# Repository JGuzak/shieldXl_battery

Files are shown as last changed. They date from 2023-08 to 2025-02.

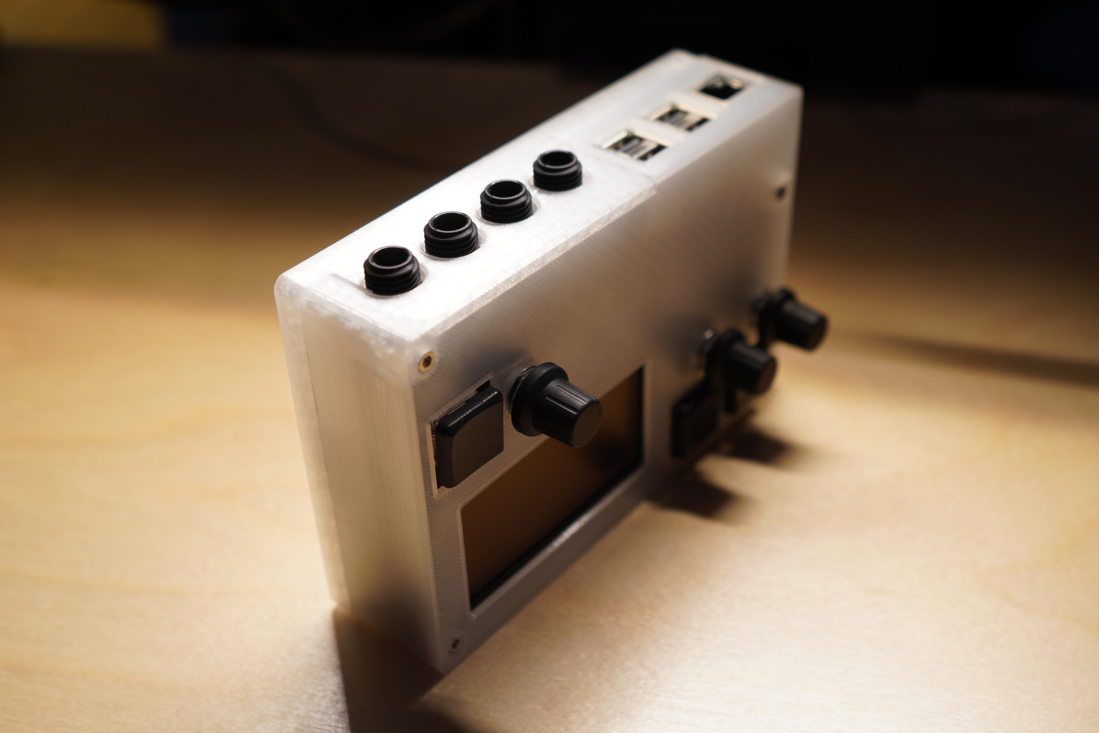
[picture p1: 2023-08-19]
images/assembled_2.JPG

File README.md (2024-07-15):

# ShieldXl Battery Case

A case and internal battery mod for the [shieldXl](https://github.com/okyeron/shieldXL/)



## DISCLAIMERS

This mod is not supported by Denki Oto and they are not responsible for assisting with assembly or troubleshooting.

The USB and Ethernet ports are aligned for raspberry pi 3B+. Raspberry pi 4 will work but the cutouts will not be aligned correctly.

## Kits for the Pi 3B+ flavor of this case are available of on the [Modbang shop](https://www.modbang.com/modbang-shop/shieldxlbatterykit).

| Table of Contents |
| - |
| Credits |
| Use |
| BOM |
| Case |
| Installation |
| Troubleshooting |



## Credits

Referenced model was designed by CarlosUnch, John Park and Steven Noreyko.

Project inspiration from Peter Kassel
FAQ/troubleshooting contributions:
- Moneo
- Teamac

## Use

Toggle the power switch to turn on the battery (Blue light will illuminate and green light should flash)

## BOM



- 1x assembled shieldxl `*` ([bom](https://github.com/okyeron/shieldXL/tree/main/bom) for the shieldXl is available over on GitHub and kits are available at the [Denki Oto Shop](http://www.denki-oto.com/))
- 1x Pisugar S Plus battery assembly (5000mAh 5 volt 3 amp)
- 1x shieldXl_battery case (see Models & Printing) `%!`
- 1x pig tail JST-PH 2.0 female header `%!`
- M2.5 bolts
  - 2x 20mm `%!`
  - 3x 16mm `%!`
  - 2x 12mm `%!`
  - 2x 10mm `%!`
  - 1x 9mm `*`
- 2x M2.5 hex nuts *4x M2.5 hex nuts if using the `bottom with hex nut.stl` file.*
- 2x M2.5 heat set inserts *None if using the `bottom with hex nut.stl` file.*
- 3x M2.5 11mm f-f standoffs `*`
- 3x encoder nuts + washers `*`
- 3x encoder caps `*`

*Items marked with `*` are included in the shieldXl kit from Denki Oto.*
*Items marked with `%!` are included in the shieldXl battery kit on the Modbang shop.*

## Case




### Models & Printing

STL made in reference to the original shieldXl case. shieldXl_battery design was made with [Blender](https://www.blender.org/) and [CAD Sketcher](https://www.cadsketcher.com/).

gcode and prusa slicer files can be found in `/prints`, stls in `/models`. Tested with PLA on Prusa MK3 and Prusa MK4 printers.

There are two flavors of top parts depending on the type of raspberry pi you use (3B+ or 4). Make sure to select the approriate stl.

There is an alternative bottom part for using hex nuts instead of heat set inserts.

## Assembly

### ShieldXl+piSugar

*!!Assemble the battery and shieldxl outside of the case and boot the device to verify things are working before attempting to install the assembly into the case!!*

1. Assemble the shieldXl
2. Using a guitar pick or similar plastic device, carefully remove the battery from both the li-po battery pack and pi sugar pcba
3. Place the pi sugar pcba against the bottom of the pi, make sure the spring loaded pin contacts are seated correctly.
4. Using the bolts included with the pisugar, attach the pisugar to the pi
5. Connect the battery to the pisugar pcba
6. *!!IMPORTANT!!* Ensure the auto startup dip switch on the bottom of the pi sugar board is set to `off`
7. Plug in the pi sugar to a charger (both usb-c and usb micro ports will charge the battery)




### Case Installation

*NOTE: The original battery header can be left on the pisugar.*

1. Insert either `2` hex nuts or `2` heat set inserts into the bottom portion of the case.




2. Remove the pi from the shieldxl pcba
3. Remove `all` standoffs from the shieldxl except for the bolt/nut through the upper right corner of the display.
4. Disconnect the battery from the pisugar pcba.
5. Carefully solder the leads of the JST pigtail to the contacts on the pisugar pcba. The original jack does not need to be removed.

*I chose to remove it because I may attempt to create a slightly thinner bottom portion of the case but this may not happen.*



6. Set the battery into the compartment on the bottom case part and attach the battery arm with `2` 10mm bolts and `2` nuts.



7. Connect the battery to the pig tail adapter.
8. Set the pisugar pcba on the bottom case with the power header side facing down.
9. Thread `3` 16mm bolts into the pisugar pcba from the bottom of the case. The bolts should be threaded all the way through the case and the pi sugar.



1.  Place the pi on top of the pisugar, ensure that the spring loaded pins on the pisugar press into the back of the gpio pins on the pi board. (A good amount of force will be needed to get the pi sugar flush with the pi)
2.  Thread the `3` standoffs up to the pi. Ensure there are no gaps between the case, pisugar, pi, or standoffs.



12. Carefully align and gentily press the shieldXl pcba onto the pi.



1.  Thread the 9mm bolt through the bottom right corner of the display and into the standoff.
2.  Carefully align and gentily press the case top onto the shieldXl. First align the left side of the case and push to the right.
3.  Thread the `2` 20mm bolts into the left holes on the top of the case.
4.  Thread the `2` remaining 12mm bolts into the right holes on the top of the case.
5.  Place the `3` washers and nuts onto the encoders and tighten by hand.
6.  Insert the micro sd card into the pi.



## Troubleshooting / FAQ

### Battery turns on but no leds on the pi turn on

Double check soldering on the pig tail extension. If the connection isn't solid, boot up behavior can be intermittent or non-functional.

### Battery and red led on pi turns on but norns doesn't boot

Double check that the micro sd card is inserted into the pi correctly.

### Pi powers up no norns display

Check that `Auto startup` is set to off.



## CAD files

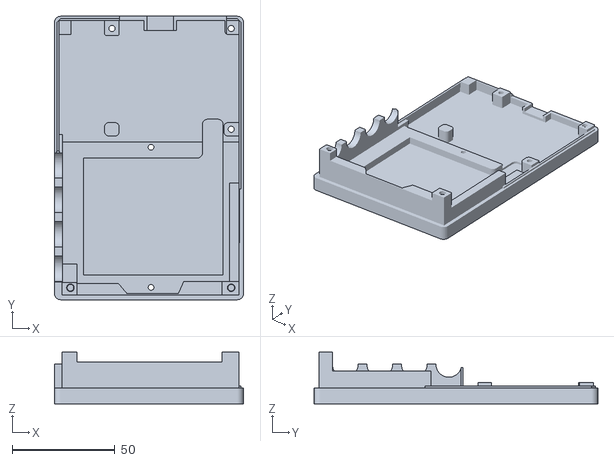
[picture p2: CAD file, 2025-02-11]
models/bottom.stl
92.0 x 138.0 x 25.2

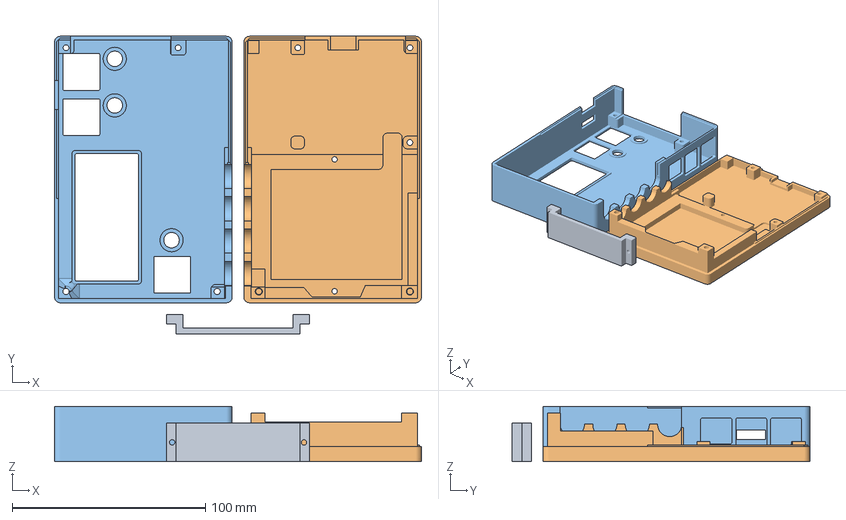
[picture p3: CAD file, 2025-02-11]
models/shieldXl_battery 4.3mf
190.0 x 154.0 x 28.7 mm
battery arm.stl
bottom.stl
top 4.stl

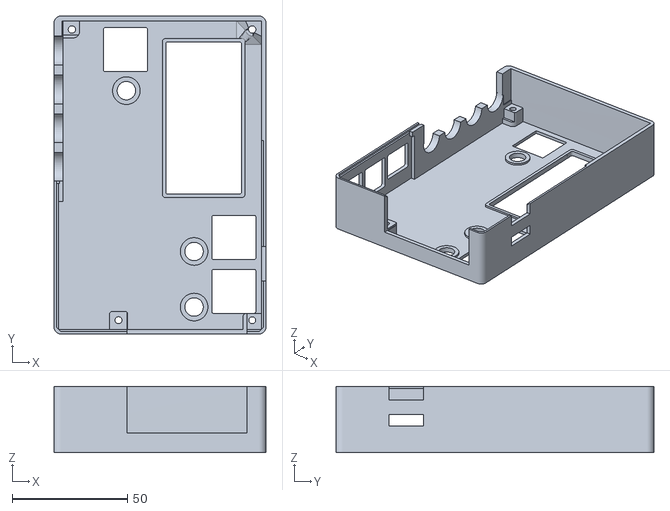
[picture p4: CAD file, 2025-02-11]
models/top 4.stl
92.0 x 138.0 x 28.7

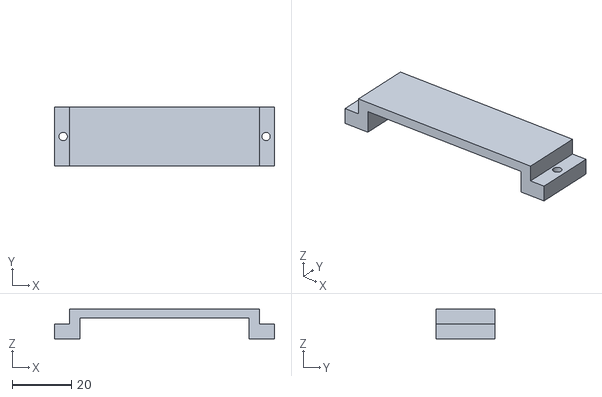
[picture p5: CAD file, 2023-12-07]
models/battery arm.stl
74.0 x 20.0 x 10.0

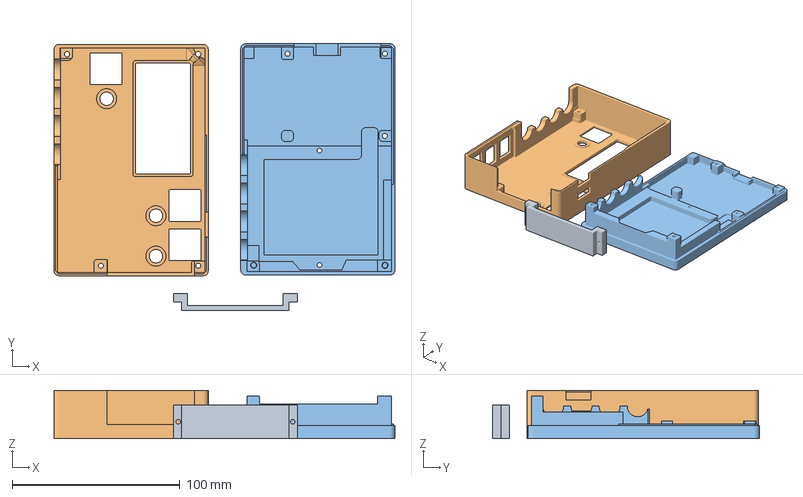
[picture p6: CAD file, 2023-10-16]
models/shieldXl_battery 3b.3mf
203.3 x 159.0 x 28.7 mm
battery arm.stl
top.stl
bottom.stl

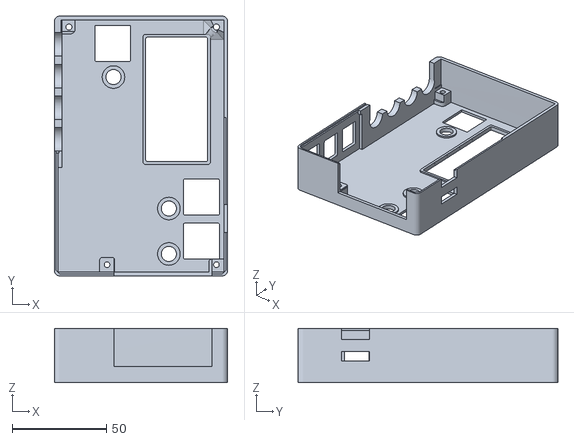
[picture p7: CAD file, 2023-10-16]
models/top 3b.stl
92.0 x 138.0 x 28.7

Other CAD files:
models/shieldXl_battery 3b hex nut.3mf
models/bottom with hex nut.stl

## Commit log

2023-07-24 work in progress
    [battery arm.stl, shieldxlbattery bottom.stl, shieldxlbattery top.stl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]
2023-07-26 refining case
2023-07-27 updating models
    [battery arm.stl, shieldxlbattery bottom.stl, shieldxlbattery top.stl]
2023-07-27 updating models and generating new gcode
    [shieldxl_battery bottom.stl, shieldxl_battery top.stl, shieldxl_battery.3mf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]
2023-08-09 improving model, adding top through holes for screws and top standoff replacements
    [battery arm.stl, shieldxl_battery bottom.stl, shieldxl_battery top.stl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]
2023-08-10 adding hardcore versions of the case, updating documentation
    [shieldxl_battery bottom hardcore.stl, shieldxl_battery bottom.stl, shieldxl_battery top hardcore no power indicator.stl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]
2023-08-11 adding hardcore mode, updating docs, updating gcode
    [bottom hardcore.stl, bottom.stl, shieldXl_battery_hardcore.3mf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]
2023-08-15 refining plusplus case, adding temp gcode, updating docs
    [bottom hardcore.stl, bottom.stl, plus bottom.stl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]
2023-08-18 adding temp images, updating print files
    [bottom.stl, plus bottom.stl, plus.3mf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]
2023-08-19 removing references to plusplus version
    [plusplus bottom.stl, plusplus toggle switch.stl, plusplus toggle test .stl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]
2023-10-16 adding heat set insert version of the bottom part, adding gap for trs MIDI output type switch, fixing tolerances between case parts, adjusting button cutout positions, fixing stl scale issues, updati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
    [bottom with hex nut.stl, bottom.stl, shieldXl_battery hex nut.3mf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]
2023-12-07 fixed missing side cutout on bottom hex nut variant
    [battery arm.stl, bottom with hex nut.stl, shieldXl_battery hex nut.3mf]
2024-05-19 adding pi 4 variant stls
    [shieldXl_battery 3b hex nut.3mf, shieldXl_battery 3b.3mf, shieldXl_battery 4.3mf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]
2024-05-24 fixing usb/ethernet jack layout
    [shieldXl_battery 4.3mf, top 4.stl]
2025-02-11 hotfix: fixing stl errors with repair algo
    [bottom.stl, shieldXl_battery 3b hex nut.3mf, shieldXl_battery 3b.3mf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]
